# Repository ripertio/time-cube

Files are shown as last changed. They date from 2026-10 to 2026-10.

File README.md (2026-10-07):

# WIP: Time Cube — ESP32-S3 Based Physical Time Tracker

A DIY physical time-tracking cube powered by an ESP32-S3 and an MPU-6050 orientation sensor. Flip the cube to switch between activity categories — no app, no cloud, no phone required. Logs are exported via a local web interface and stored on the ESP, or exported to your device

## Features

- **Orientation-based tracking** — each face of the cube represents a different activity
- **Standalone** — runs on your local network with no cloud dependency or app lock-in
- **Open source** — fully customizable via ESPHome
- **LED status feedback** — onboard WS2812B RGB LED indicates connection and tracking state
- **Battery powered** — LiPo with TP4056 charging circuit

---

## Hardware

| Component | Specification |
| --- | --- |
| MCU | ESP32-S3 SuperMini |
| IMU | MPU-6050 (I2C) |
| LED | Onboard WS2812B |
| Battery | LiPo 400–500 mAh |
| Power Switch | Sliding Switch |
| Enclosure | 3D-printed, ~5×5×5 cm |

### Wiring (I2C)

| MPU-6050 Pin | ESP32-S3 Pin |
| --- | --- |
| SDA | GPIO 8 |
| SCL | GPIO 9 |
| VCC | 3.3V |
| GND | GND |
| Reset Button | GPIO |

> Adjust GPIO pins to match your specific wiring if different.

---

## Software

The firmware is built with [ESPHome](https://esphome.io/). The configuration file is located in [](ESPHome_config/).

To flash or inspect logs, use the ESPHome web installer: [web.esphome.io](https://web.esphome.io/?dashboard_install)

### LED States

| State | Color  | Pattern |
| --- | --- | --- |
| Boot / WiFi connecting | Yellow | Slow blink |
| Ready / idle | Off | — |
| Debounce in progress | White  | Dim solid  |
| Face change detected | Green  | On for 5 s |
| WiFi error | Red | Fast blink |

### Side / Face Configuration

Each face (1–6) maps to an activity category. You can configure the labels via the ESPHome web portal at `http://timecube.local` (or the IP address shown in the boot logs).

To find your cube's hostname or IP:
1. Connect the cube via USB to your computer
2. Open [web.esphome.io](https://web.esphome.io/?dashboard_install) and view the device logs
3. After boot and WiFi connection, the assigned IP address is printed in the log

---

## Getting Started

### 1. Flash the firmware

1. Connect the cube via USB
2. Go to [web.esphome.io](https://web.esphome.io/?dashboard_install)
3. Select the device and flash the config from `ESPHome_config/`

### 2. First boot & WiFi setup

1. Power on the cube
2. Connect your phone or laptop to the cube's WiFi hotspot (no password)
3. Follow the captive portal to connect the cube to your local WiFi

### 3. Track your time

1. Open `http://timecube.local` (or the cube's IP) in a browser
2. Configure which activity each face represents
3. Flip the cube to start tracking — the active face is logged automatically
4. Export your time logs from the web interface (e.g. http://timecube.local/text_sensor/csv_export)

---

## License

MIT

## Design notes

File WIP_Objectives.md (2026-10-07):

# Project Objectives

## Stage 0 — Hardware & Enclosure

### Procurement & Assembly
- [x] Order all hardware components
- [x] Wire up components 
    - [x] ESP32-S3
    - [x] MPU-6050, 
    - [x] battery
    - [x] on/off switch
    - [x] reset button

### 3D Design & Printing
- [x] Create initial sketch / concept drawing
- [x] Ask for help with CAD design
- [x] Draft CAD model
  - Cube body: ~50×50×50 mm outer dimensions
  - Wall thickness: 1.5–2 mm for semi-transparency
  - Internal standoffs / snap-fits to hold PCB and battery in place
  - Cutouts: USB-C port, sliding power switch, diffuser window for LED
  - Lid or bottom panel that clips or screws shut for easy access
- [x] Buy transparent / translucent PLA (natural or white for LED glow)
- [x] Slice and print prototype
  - Infill: 12-15% (gyroid) to keep walls thin and light diffusion even
- [x] Test fit: verify all components fit, check LED glow through walls
- [ ] Iterate: refine tolerances, adjust wall thickness if needed

---

## Stage 1 — Orientation Detection
- [x] Read MPU-6050 via I2C
- [x] Determine active face (1–6) using gravity threshold on each axis
- [x] Serial monitor output for debugging

---

## Stage 2 — LED Feedback
- [x] Implement NeoPixel LED states
- [x] 2-second debounce logic to avoid spurious face changes
- [ ] 25-minute Pomodoro timer with LED indicator

---

## Stage 3 — WiFi & Time
- [x] WiFiManager hotspot onboarding (captive portal on first boot)
- [x] NTP time sync

---

## Stage 4 — Data Storage
- [x] Local storage on device
- [x] Write CSV log entries: `timestamp, face, activity, duration_sec`

---

## Stage 5 — Web Interface
- [ ] Activity dashboard with live status
- [ ] Per-face activity label configuration
- [ ] CSV export / download
- [x] Analytics page (`analytics.html`) — pie charts, monthly breakdown, daily view

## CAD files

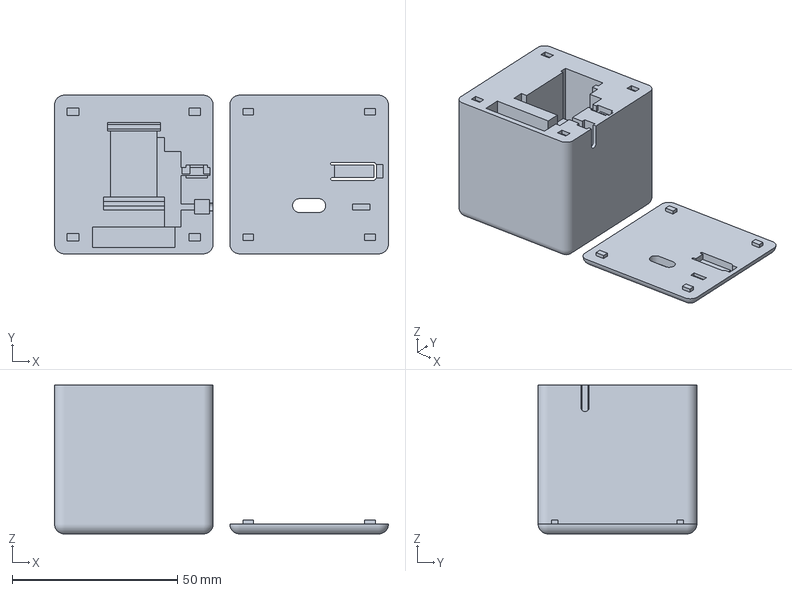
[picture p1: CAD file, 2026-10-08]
3D_files/time-cube.3mf
101.0 x 48.0 x 45.0 mm

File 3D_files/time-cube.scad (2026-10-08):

// time-cube.scad
// 50mm cube with 3mm-radius rounded corners/edges,
// split into a base and a cover exactly 3mm from the top face.

size = 48;          // overall cube edge length [mm]
corner_r = 3;        // corner/edge rounding radius [mm]
split_h = 3;         // height of the cover slice, measured parallel to the top edge [mm]
gap = 90;            // visual separation between base and cover when previewing

// Manifold repair epsilon: prevents z-fighting artifacts in OpenSCAD rendering
eps = 0.01;          // small overlap/clearance to avoid floating-point precision issues
eps2 = 0.02;         // double epsilon for larger relief cuts

inner_cavity_depth = 28; // height of the upper internal cavity where the parts sit [mm]
inner_cavity_wall = 2;   // wall thickness around the internal cavity [mm]

snap_tab_inset = 4;       // distance of the snap tabs from the cover edge [mm]
snap_tab_width = 3.2;     // width of each snap tab [mm]
snap_tab_depth = 2.0;     // depth of each snap tab measured along the edge [mm]
snap_tab_height = 1.2;    // how far the tab protrudes below the lid [mm]
snap_recess_extra = 0.3;  // extra clearance for the matching recess [mm]

battery_length = 25;  // battery pocket length, along X [mm]
battery_width = 6.2;    // battery pocket width, along Y [mm]
battery_depth = 44;   // battery pocket depth, along Z, kept shallow so it sits in the upper cavity [mm]
battery_offset_y = 2; // distance from the pocket to the nearest Y side surface [mm]

mpu_length = 26;          // MPU board height, stands vertically along Z [mm]
mpu_width = 16;           // MPU board width, along X [mm]
mpu_pcb_height = 1.4;     // bare PCB thickness -> width (Y) of the bottom registration shelf [mm]
mpu_pcba_height = 2.5;    // populated PCBA thickness -> width (Y) of the main clearance slot [mm]
mpu_register_height = 2;  // height (Z) of the bottom registration shelf that grips the bare board edge [mm]

esp_length = 23.7;         // ESP32-S3-mini board height, stands vertically along Z [mm]
esp_width = 18.5;          // ESP32-S3-mini board width, along X [mm]
esp_pcb_height = 1.4;      // bare PCB thickness -> width (Y) of the bottom registration shelf [mm]
esp_pcba_height = 4;       // populated PCBA thickness -> width (Y) of the main clearance slot [mm]
esp_register_height = 1;   // height (Z) of the bottom registration shelf that grips the bare board edge [mm]
esp_gap_from_mpu = 20;     // gap between the MPU pocket and the ESP pocket, along Y [mm]

// The side switch remains in the X=size wall. The extra tactile switch is now
// mounted actuator-up beneath a flexure in the snap-fit cover.
switch_length = 9;             // switch body length, along Z when side-mounted [mm]
switch_width = 4;              // switch body width, along Y [mm]
switch_body_depth = 4;       // switch body depth, along X [mm]
switch_fit_clearance = 0.4;    // total clearance around the switch body [mm]
switch_pin_height = 5;         // terminal clearance depth inward from the body [mm]
switch_pin_channel_width = 1.8; // terminal wire channel width, along Y [mm]
switch_access_length = 7;      // side slot length, along Z [mm]
switch_access_width = 2.5;     // actuator channel width, along Y [mm]
switch_side_wall_thickness = 1.2; // remaining outer wall thickness at the switch [mm]

// 3x6x4.5mm tactile button, rotated actuator-up beneath the cover tongue.
// In the new orientation its 6mm body dimension and 6.5mm terminal pitch run
// along X. The two pin wells connect through a shallow passage below the body.
button_length = 6;              // switch body length along X [mm]
button_width = 3.5;             // switch body width along Y [mm]
button_side_depth = 3.9;        // body/actuator stack height along Z [mm]
button_actuator_length = 3.2;   // actuator dimension retained from the switch spec [mm]
button_actuator_width = 1.8;    // actuator width [mm]
button_fit_clearance = 0.4;     // total clearance around the switch body [mm]
button_pin_size = 1.6;          // terminal clearance square, along X and Y [mm]
button_pin_depth = 6.0;         // pin clearance down to the wire trench [mm]
button_pin_offset_x = 3.25;     // 6.5mm terminal pitch, centered along X [mm]

// Flush top-cover flexure. A U-shaped through-slot isolates the tongue; an
// underside relief leaves a thin top skin and room for the switch body.
button_flexure_length = 13.5;         // tongue length, along X [mm]
button_flexure_slot_width = 0.8;      // rounded through-slot width [mm]
button_flexure_track_spacing = 4.6;   // distance between parallel slot centers [mm]
button_flexure_skin_thickness = 1.0;  // remaining top skin at the tongue [mm]
button_flexure_switch_gap = 0.2;      // clearance above the unpressed actuator [mm]

// Y-axis layout: battery, then switch/button row, then ESP, then MPU.
// Each pocket's Y footprint is bounded by its wider (PCBA) clearance slot.
// The ESP pocket is mirrored 180° around its center so the USB-side of the board
// sits on the opposite edge from the LED-side placement.
row_gap_from_battery = 2;   // gap between the battery pocket and the switch/button row [mm]
esp_gap_from_row = -3;       // gap between the switch/button row and the ESP pocket [mm]
row_y_start = battery_offset_y + battery_width + row_gap_from_battery;
row_y_center = row_y_start + max(switch_width, button_length) / 2;
row_y_end = row_y_start + max(switch_width, button_length);
esp_y_start = row_y_end + esp_gap_from_row;
esp_y_center = esp_y_start + esp_pcba_height / 2;
mpu_y_start = esp_y_start + esp_pcba_height + esp_gap_from_mpu;
mpu_y_center = mpu_y_start + mpu_pcba_height / 2;

// Cable channel between the ESP and MPU pockets: a trench cut into the top of the
// base, open at the mating face, that fills the whole gap between the two boards'
// clearance slots. Leaves each board's registration shelf/pcb-width slot mostly
// untouched, while giving the 4 interconnect wires a path that isn't pinched
// when the cover is fitted.
cable_channel_width = 14;       // channel size along X, room for the 4 wires [mm]
cable_channel_depth = 18;     // channel depth (Z) below the mating face [mm]
cable_channel_y_start = esp_y_start + esp_pcba_height - 0.5; // overlap into the ESP slot slightly
cable_channel_y_end = mpu_y_start + 0.5;                   // overlap into the MPU slot slightly
cable_channel_length = cable_channel_y_end - cable_channel_y_start; // spans the ESP/MPU gap with grip overlap
cable_channel_relief_length = mpu_y_start - cable_channel_y_start - 2; // stop side relief at the MPU pocket edge

// USB-C charging slot in the cover, above the ESP32-S3-mini's top edge, where its
// USB-C socket is soldered face-up on the PCB -- long axis runs along X (board width).
usbc_slot_length = 10;    // long-axis (X) size of the USB-C cutout [mm]
usbc_slot_width = 4.2;   // short-axis (Y) size of the USB-C cutout [mm]
usbc_x_center = size / 2;      // aligned with the ESP pocket's X center
usbc_y_center = esp_y_center + esp_pcba_height / 2 - usbc_slot_width / 2 - 0.5; // toward the ESP's outer edge

// Controls are side by side along Y on the X=size wall, away from the ESP pocket.
switch_y_center = row_y_center + 1;
button_gap_switch = 7b;
button_y_center = switch_y_center + switch_width / 2 + button_gap_switch + button_width / 2;
switch_z_center = size - split_h - switch_length / 2;
button_top_x_center = 43;       // same side location as before, just inside the +X rim [mm]
button_top_y_center = button_y_center; // preserve the original button row [mm]
button_switch_top_z = size - button_flexure_skin_thickness - button_flexure_switch_gap;
button_body_bottom_z = button_switch_top_z - button_side_depth;
button_flexure_root_x = 30.5;   // root is inward of the actuator, clear of USB-C and snap features [mm]
button_flexure_tip_x = button_flexure_root_x + button_flexure_length;
button_flexure_slot_z = size - split_h / 2;
button_flexure_relief_x = button_flexure_root_x + 1.2;
button_flexure_relief_width = button_flexure_tip_x + 0.2 - button_flexure_relief_x;
button_wire_spur_height = 2.2;  // shallow pin-wire route below the switch floor [mm]
button_wire_channel_width = 2.4; // passage width under the switch, joining both pin wells [mm]
button_pin_open_channel_width = 2.4; // open lead groove width along X, routed toward +Y [mm]

// Switch slot extends upward to the cover seam, keeping its original lower edge.
// The slot bottom sits at (switch_z_center - switch_access_length/2).
// We extend it upward to the mating face, creating an overrun that makes
// the slot full-width (access_width → full width via half-width chamfer).
switch_slot_bottom_z = switch_z_center - switch_access_length / 2;
switch_slot_top_z = size - split_h;  // mating face (cover seam)
switch_access_cut_length = switch_slot_top_z - switch_slot_bottom_z + switch_access_width / 2;
switch_access_cut_z_center = switch_slot_bottom_z + switch_access_cut_length / 2;
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

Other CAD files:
3D_files/time-cube.stl

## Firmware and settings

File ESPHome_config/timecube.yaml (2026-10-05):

esphome:
  name: timecube
  friendly_name: Time Cube
  
  includes:
    - timecube_storage.h
  
  on_boot:
   - priority: -100
     then:
       - lambda: |-
          ESP_LOGI("timecube", "Time Cube gestartet!");
          setup_littlefs();
          load_config();

esp32:
  board: esp32-s3-devkitc-1
  framework:
    type: esp-idf
  partitions: partitions_timecube.csv

# ... (Rest bleibt EXAKT GLEICH wie vorher!)

# WiFi Configuration (keine hardcoded Credentials!)
wifi:
  ap:
    ssid: "TimeCube Setup"
    password: ""
  on_connect:
    then:
      - lambda: |-
          id(wifi_connected) = true;
          id(wifi_ever_connected) = true;
  on_disconnect:
    then:
      - lambda: |-
          id(wifi_connected) = false;

# Captive Portal für WiFi Setup
captive_portal:

# Improv Serial für USB-Setup über Browser
improv_serial:

# Enable logging
logger:
  level: INFO # DEBUG
  logs:
    mpu6050: INFO
    sensor: INFO
    web_server: INFO


api:
  services:
    # Namen ändern
    - service: set_activity_name
      variables:
        side: int
        name: string
      then:
        - lambda: |-
            set_activity_name(side, name);
            id(activity_side_1).update();
            id(activity_side_2).update();
            id(activity_side_3).update();
            id(activity_side_4).update();
            id(activity_side_5).update();
            id(activity_side_6).update();
    
    # CSV Export triggern
    - service: export_csv
      then:
        - lambda: |-
            id(csv_export).update();
    
    # Log löschen
    - service: clear_log
      then:
        - lambda: |-
            clear_log();
            id(csv_export).update();
            id(log_count).update();
# Enable OTA updates
ota:

# Web Server for Dashboard + WiFi Management
web_server:
  port: 80
  version: 3

# Time Component (NTP)
time:
  - platform: sntp
    id: sntp_time
    timezone: Europe/Berlin

# I2C Bus for MPU-6050
i2c:
  sda: GPIO8
  scl: GPIO9
  scan: true
  frequency: 100kHz
  
light:
  - platform: esp32_rmt_led_strip
    id: status_led
    pin:
      number: 48
    num_leds: 1
    chipset: WS2812
    rgb_order: GRB
    name: "Status LED"
    default_transition_length: 0s


# MPU-6050 Sensor
sensor:
  - platform: mpu6050
    address: 0x68
    update_interval: 200ms
    accel_x:
      name: "Accel X"
      id: accel_x
      internal: true
    accel_y:
      name: "Accel Y"
      id: accel_y
      internal: true
    accel_z:
      name: "Accel Z"
      id: accel_z
      internal: true

  - platform: wifi_signal
    name: "WiFi Signal"
    update_interval: 60s

  - platform: template
    name: "Current Side"
    id: current_side
    update_interval: 3s
    lambda: |-
      float x = id(accel_x).state;
      float y = id(accel_y).state;
      float z = id(accel_z).state;
      
      if (z > 8.0) return 1;
      if (z < -8.0) return 2;
      if (y > 8.0) return 3;
      if (y < -8.0) return 4;
      if (x > 8.0) return 5;
      if (x < -8.0) return 6;
      
      return id(current_side).state;
    on_value:
      then:
        - script.execute: handle_side_change

  - platform: template
    name: "Activity Duration"
    id: activity_duration
    unit_of_measurement: "s"
    accuracy_decimals: 0
  
  # ← HIER FEHLT LOG COUNT!
  - platform: template
    name: "Log Count"
    id: log_count
    update_interval: 60s
    accuracy_decimals: 0
    lambda: |-
      return get_log_count();

# Text Sensor for Activity Name
text_sensor:
  - platform: template
    name: "Current Activity"
    id: current_activity
    update_interval: never
    lambda: |-
      int side = (int)id(current_side).state;
      return get_activity_name(side);
  
  # CSV Export
  - platform: template
    name: "CSV Export"
    id: csv_export
    update_interval: never
    lambda: |-
      return get_csv_content();
  
  # Seitennamen als Text Sensors
  - platform: template
    name: "Activity Side 1"
    id: activity_side_1
    internal: true
    update_interval: 60s
    lambda: |-
      return get_activity_name(1);
  
  - platform: template
    name: "Activity Side 2"
    id: activity_side_2
    internal: true
    update_interval: 60s
    lambda: |-
      return get_activity_name(2);
  
  - platform: template
    name: "Activity Side 3"
    id: activity_side_3
    internal: true
    update_interval: 60s
    lambda: |-
      return get_activity_name(3);
  
  - platform: template
    name: "Activity Side 4"
    id: activity_side_4
    internal: true
    update_interval: 60s
    lambda: |-
      return get_activity_name(4);
  
  - platform: template
    name: "Activity Side 5"
    id: activity_side_5
    internal: true
    update_interval: 60s
    lambda: |-
      return get_activity_name(5);
  
  - platform: template
    name: "Activity Side 6"
    id: activity_side_6
    internal: true
    update_interval: 60s
    lambda: |-
      return get_activity_name(6);
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

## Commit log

2026-07-17 added download csv button
2026-10-05 Draft of OpenScad file for time cube
    [time-cube.scad]
2026-10-05 Adapting the cover closure
    [time-cube.scad]
2026-10-06 adapting the access of the the on off switch
    [time-cube.3mf, time-cube.scad, time-cube.stl]
2026-10-06 improving readability and size of the cable channel for better view
    [time-cube.3mf, time-cube.scad, time-cube.stl]
2026-10-07 improving access to on/off switch
    [time-cube.scad]
2026-10-07 adding Flex lid
    [time-cube.scad]
2026-10-07 commented out screw patterns
    [time-cube.scad]
2026-10-07 remove screw pattern
    [time-cube.scad]
2026-10-07 small adpations to fit the button and the on off switch
    [time-cube.scad]
2026-10-08 moving button to the top - stronger tounge
    [time-cube.3mf, time-cube.scad, time-cube.stl]
2026-10-19 update readme based on current work
2026-10-21 edding pomodori timer - with config options in webUI
2026-10-21 trying to impelment extra button functionallity
2026-10-24 Changing Pin for Button (it is 13)
2026-10-27 improving access to +/- Solderjoints of ESP
2026-10-28 changing order of LED priority
